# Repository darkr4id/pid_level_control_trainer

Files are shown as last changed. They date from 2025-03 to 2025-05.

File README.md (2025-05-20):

# MATLAB+Simulink based PID Fluid level control trainer - Bachelor Thesis project.
This repository contains all the materials associated with the Bachelor thesis project on a **MATLAB based PID Fluid level trainer**. The work focuses on developing and implementing a PID controller for fluid level regulation, with a detailed analysis presented in the thesis document.

## Table of Contents

- [Overview](#overview)
- [Project Structure](#project-structure)
- [Getting Started](#getting-started)
- [Usage](#usage)
- [Key Features](#key-features)
- [Results](#results)
- [Acknowledgements](#acknowledgements)
- [License](#license)

This repository contains the complete materials for the Bachelor thesis project titled "MATLAB based PID Fluid level trainer." The project focuses on designing and implementing a fluid level trainer using a MATLAB-based PID controller. The files in the repository include:

MATLAB Code: Scripts and functions for implementing the PID controller, running simulations, and analyzing fluid level control.
Supporting Materials: MATLAB Code, Simulink Models, and supplementary documentation that support the thesis findings.
Additionally a GUI program is included to run both the simulations and the experiment methods in a graphical environment.* 
The project demonstrates the practical application of control theory using MATLAB, where a PID controller is developed and tuned to regulate the fluid level in a training environment.

## Overview

This project explores the design, simulation, and implementation of a Proportional-Integral-Derivative (PID) controller to regulate fluid levels in a training setup. The main objectives include:

- **Design and Simulation:** Creating a model of the fluid level system in MATLAB.
- **PID Tuning:** Experimenting with different PID parameters to achieve optimal performance.
- **Analysis:** Documenting system responses and comparing simulation results with theoretical expectations.
- **Implementation:** Integrating the PID controller within a practical fluid level training system.

## Project Structure

The repository is organized as follows:

- README.md : This file
- p_f2.m : Main automation script
- pid_exp.slx : Main experimental simulink model
- pid_sim.slx : Main simulation model
- gui_pid_simulation_2.m : GUI Program for the project (Beta)

To run the MATLAB Simulink models and explore the PID controller design:

1. **Clone the repository:**

   ```bash
   git clone https://github.com/darkr4id/pid_level_control_trainer.git
   cd pid_level_control_trainer
2. **Open MATLAB:**

Navigate to the matlab/ directory and open the primary simulation script (pid_sim.slx) and the experimental simulink model (pid_exp.slx).
GUI Program at 
Run the Simulation:

**Important**
The experimental setup is designed using a Arduino UNO R4, therefore its essential for any replications of the setup to have the same microcontroller or for the Simulink external mode settings to be adjusted according to the controller used.
Motor Driver: L298N
Pump: Brushed DC pump of 12V (Exact model can be found on the Thesis Defence presentation)

**Important**
The GUI program was in the beta version as of 2025 May, no further development would be available for it due to time constraints and due to me finally moving on from this project to my master, but the GUI program worked just fine except for some minute errors in handling the experimental mode with multiple gain combos.

Execute the script in MATLAB. Make sure you have the necessary toolboxes installed, Arduino Support package for simulink and matlab, Digital signal processing toolbox. Adjust the PID parameters in p2_f.m when running the script.

Usage
Simulation: Run the fluid_level_simulation.m script to simulate the fluid level control.
Analysis: Check the generated plots and logs for performance analysis.
Experimentation: Modify the PID gains in the pid_controller.m file to observe different system responses.
Key Features
PID Controller Implementation: Robust PID algorithm tailored for fluid level control.
Simulation Environment: Detailed MATLAB simulation of a fluid tank system.
Data Analysis: Integrated tools for performance evaluation with plots and data logging.
Documentation: Comprehensive thesis report and supplementary documentation to support the findings.
Results
The project demonstrates successful control of fluid level dynamics using the PID controller. The simulation results indicate that with appropriate tuning, the system can maintain the fluid level within desired limits while responding effectively to disturbances.

## Acknowledgements
Special thanks to supervisors Prof Frank Platte and Dr. Peter Henselder, friends and family that supported this project. 

* In the GUI program specifically when its in the experimental mode at times it had issues with communicating with Matlab, but this can mostly be resolved by resetting the Arduino and relaunching Matlab.

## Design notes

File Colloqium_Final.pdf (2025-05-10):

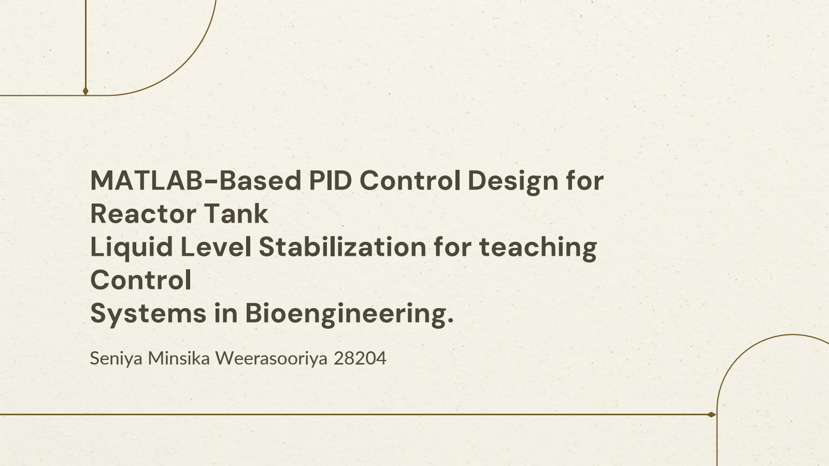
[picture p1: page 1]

# MATLAB-Based PID Control Design for

# Reactor Tank

# Liquid Level Stabilization for teaching Control

Systems in Bioengineering.

Seniya Minsika Weerasooriya 28204

# Introduction

01

1

# Fluid Level Control Systems

## Why do we need them?

- Provides hands on experience with different control strategies.
- Study the effects of varying Proportional, Integral and Derivative gains.
- Ensures the product quality by precise control of fluid levels in operations
- Ensures safety by preventing of overflows and other equipment malfunctions and overall stability of the system.

## Educational Significance

# Commercially available solutions

- Used to teach and demonstrate P, PI and PID control systems.
- Gunt RT 10
- Amatrol Level/Flow Process Control Troubleshooting Training System
- Prohibitive device cost
- Difficult to acquire for some institutions due to logistical complications.

## Purpose

## Commercially available liquid level control trainers

## Drawbacks

Fig 1 Gunt RT 10

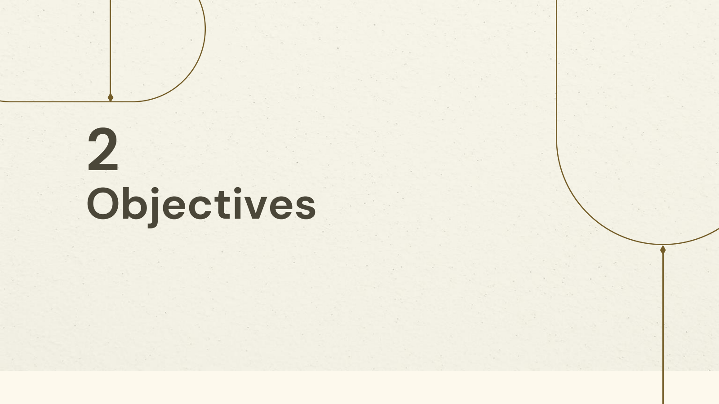
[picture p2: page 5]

# Objectives

2

# Objectives

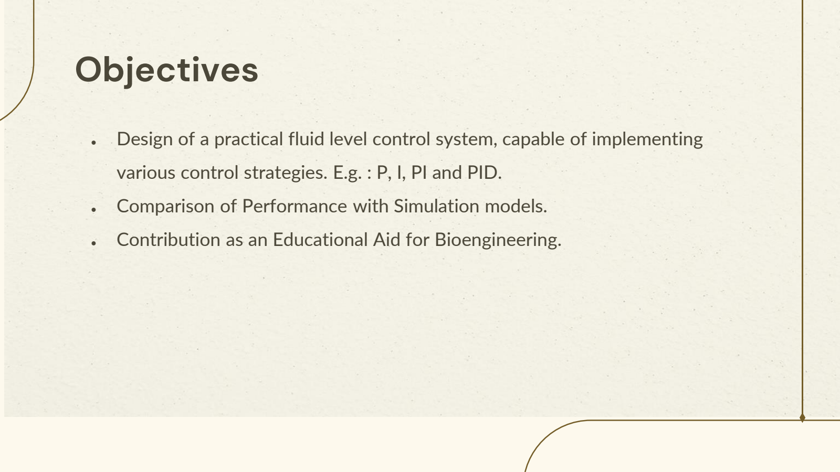
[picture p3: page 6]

- Design of a practical fluid level control system, capable of implementing various control strategies. E.g. : P, I, PI and PID.
- Comparison of Performance with Simulation models.
- Contribution as an Educational Aid for Bioengineering.

# Theoretical framework

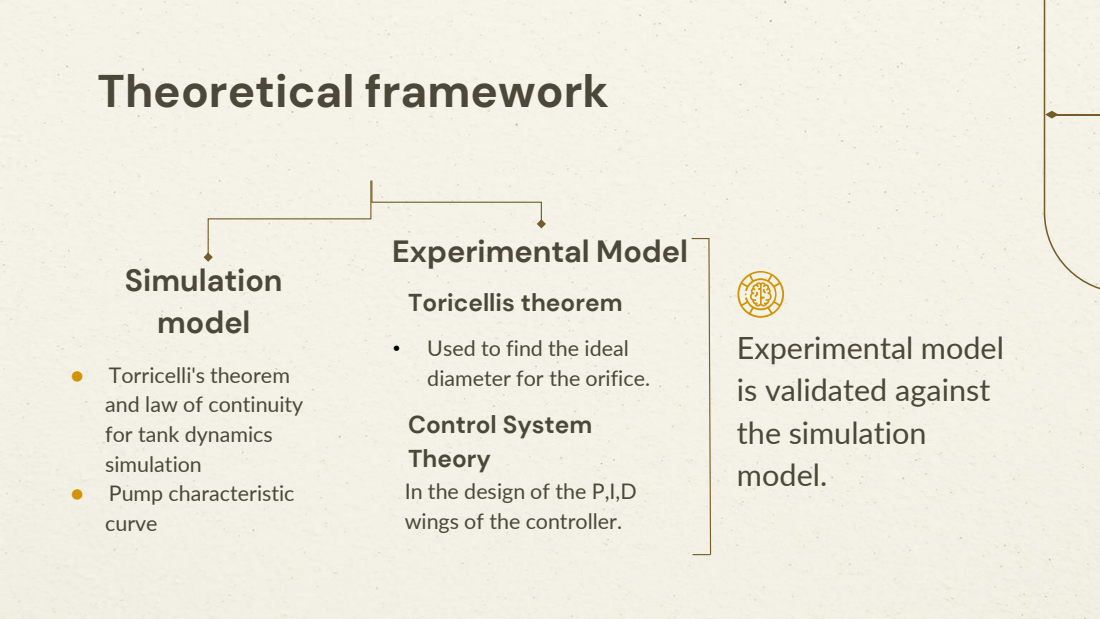
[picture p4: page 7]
Simulation model

Experimental Model
Toricellis theorem
• Used to find the ideal
diameter for the orifice.
Control System
Theory
In the design of the P,I,D
wings of the controller.

Experimental model
is validated against
the simulation
model.

● Torricelli's theorem
and law of continuity
for tank dynamics
simulation
● Pump characteristic
curve

# Design and Implementation

3

# The process :Experimental Setup

## Main Components

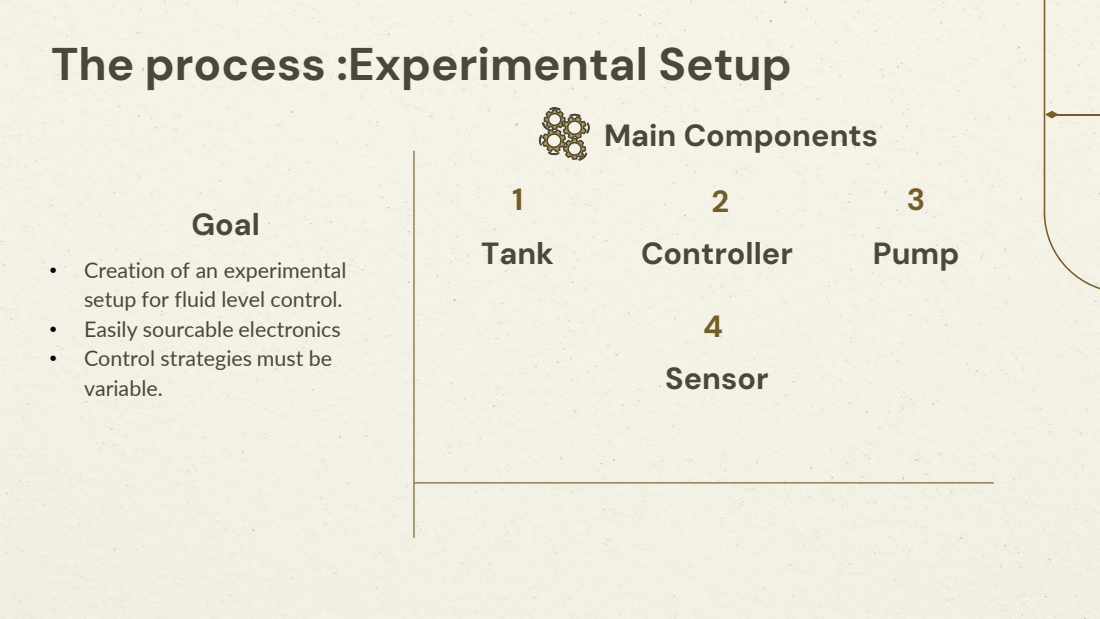
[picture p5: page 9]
Goal; Tank; Controller; Pump; Sensor

• Creation of an experimental
setup for fluid level control.
• Easily sourcable electronics
• Control strategies must be
variable.

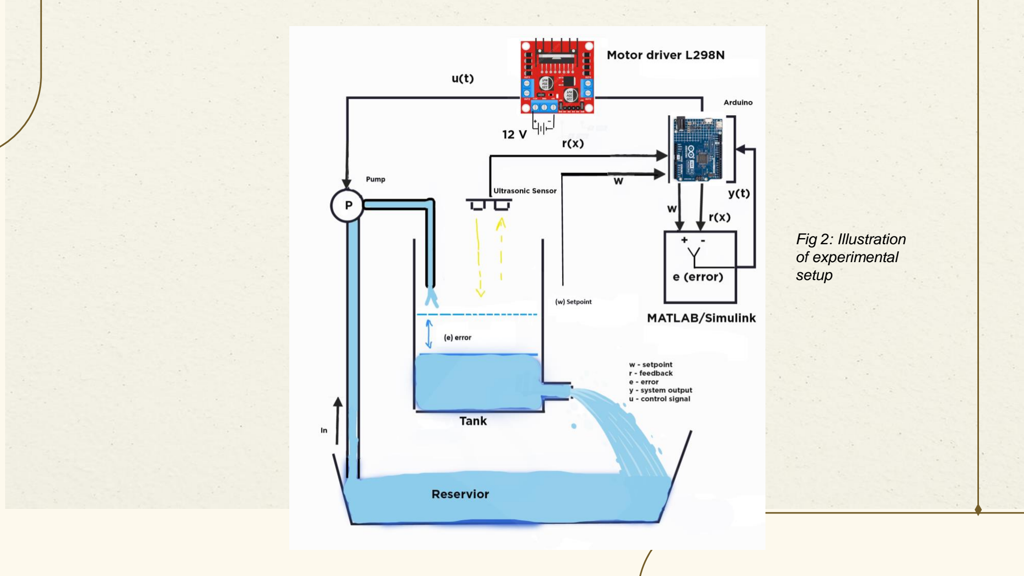
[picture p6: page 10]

Fig 2: Illustration
of experimental
setup

# Tank

- Glass tank with an orifice drilled on the bottom.
- Diameter = 15 cm
- Original orifice diameter = 14 mm
- Height = 0.2 m
- Printed orifice diameter = 4 mm (design), 3.5 mm (experimental)

### Custom Designed Outflow Pipe

# Experimental Model (Hardware Design)

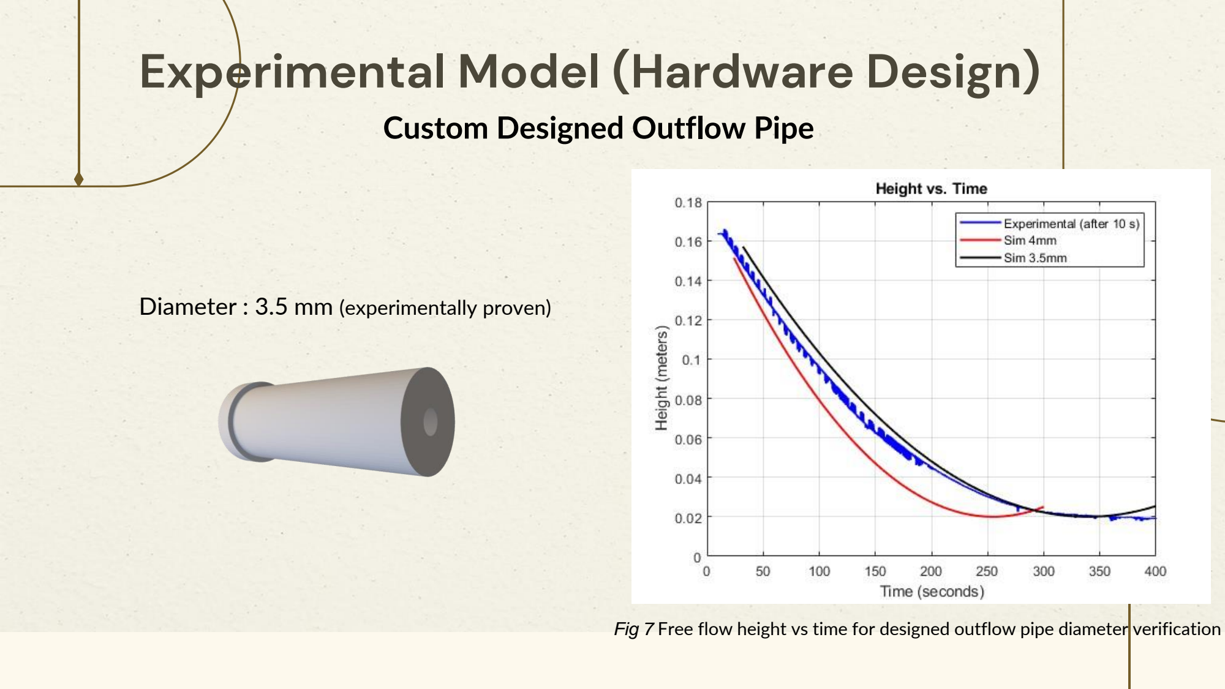
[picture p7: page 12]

Diameter : 3.5 mm (experimentally proven)

Fig 7 Free flow height vs time for designed outflow pipe diameter verification

# Controller

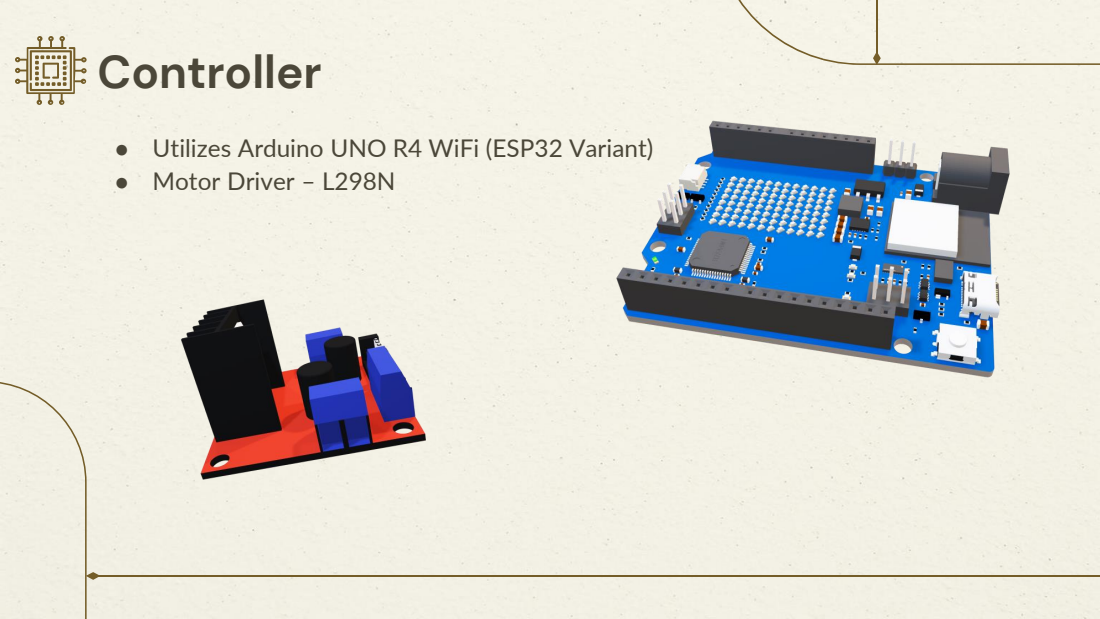
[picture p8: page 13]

● Utilizes Arduino UNO R4 WiFi (ESP32 Variant)
● Motor Driver – L298N

# Pump

- R385 Diaphragm Pump 12V
- Max flow rate
23 mL/sec experimental value
*26 ml/sec in datasheet

# Sensor

- SR04 Ultrasonic Sensor | Fig 3 Pumping curve for R385

Fig 4 R385

Fig 5 SR04 Ultrasonic Sensor

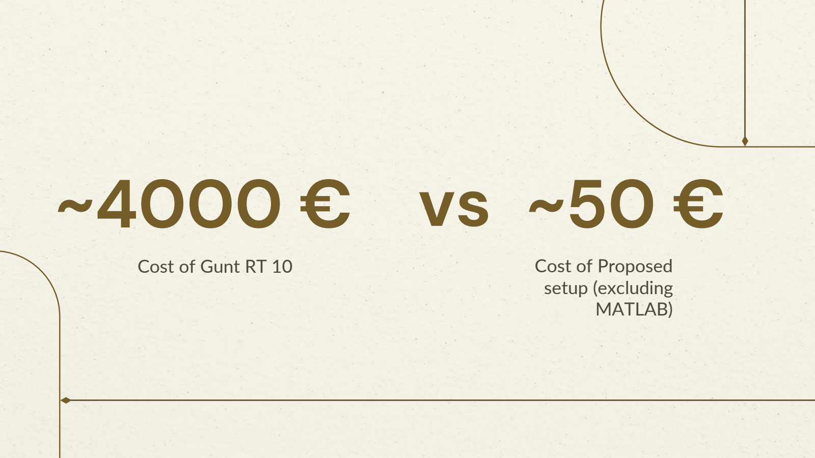
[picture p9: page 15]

~4000 €

Cost of Gunt RT 10

~50 €

Cost of Proposed
setup (excluding
MATLAB)

vs

# Methodology

4

# Nonlinear Simulation Model

# Nonlinear Simulation Model

Control Strategy (P/I/D)

# Nonlinear Simulation Model

Pump Dynamics Simulation

# Nonlinear Simulation Model

Tank dynamics Simulation

- A = pi*(0.15^2)/4 (Diameter of tank)
- a = pi*(0.0035^2)/4 (Outflow diameter)
- | C = a*sqrt(2*9.8) | (a* 2g)

# The Experimental model

Fig 6 Experimental Setup

# Experimental Model (Simulink Model)

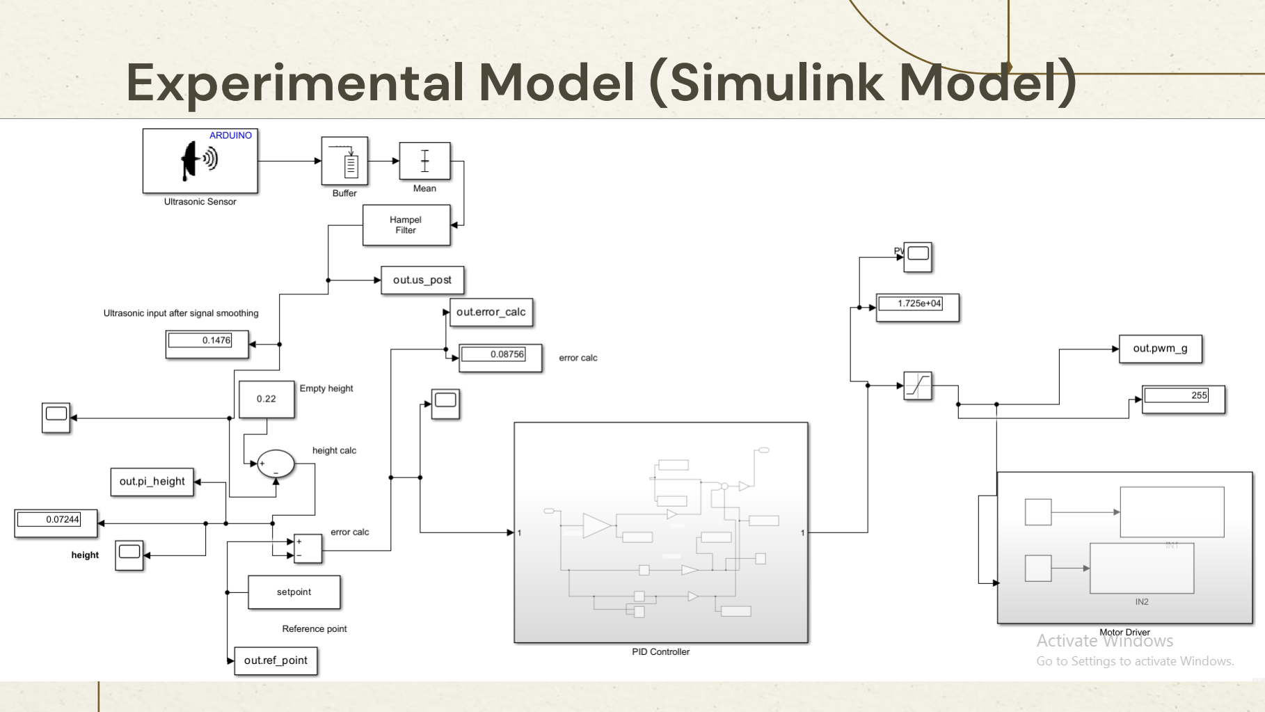
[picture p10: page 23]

Pump Dynamics Simulation

# Experimental Model (Simulink Model)

US Sensor input and Signal Processing for Noise reduction and Outlier elimination

# Experimental Model

Height and Error calculation from Ultrasonic data

# Experimental Model

PID Controller

# Experimental Model

PID Controller Subsystem

# Experimental Model

PWM to Pump

# Experimental Model

PWM Input

Motor ON/OFF and
Polarity control

### Tank Cover

# Experimental Model (Hardware Design)

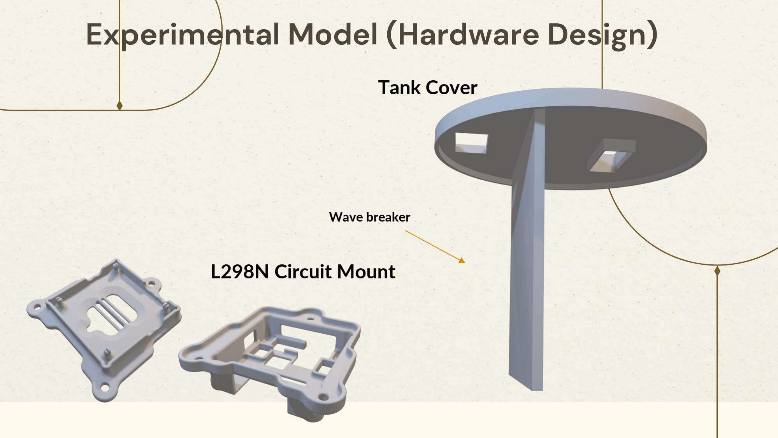
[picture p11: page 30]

### L298N Circuit Mount

Wave breaker

# Automation of Experiments

Fig 8 Automation Script code snippet

# Remote Execution of

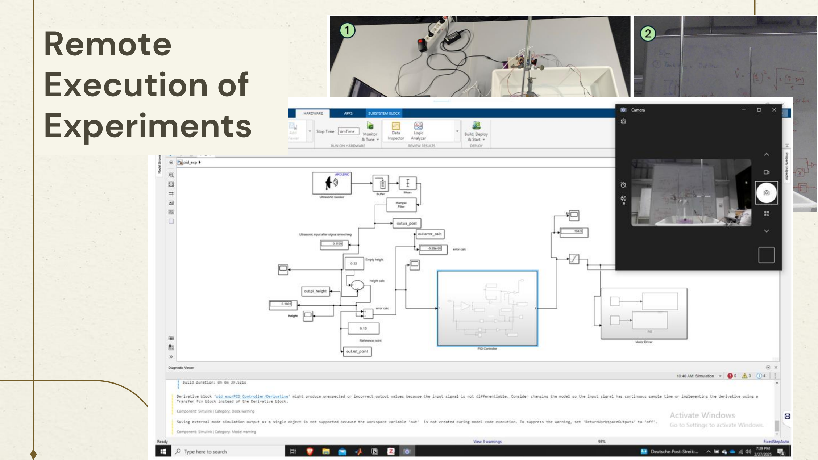
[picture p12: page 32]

# Experiments

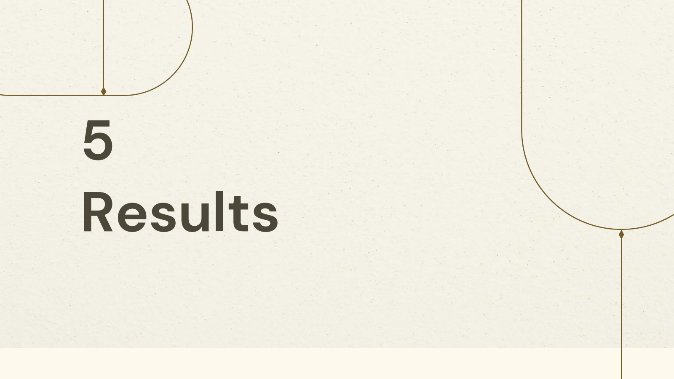
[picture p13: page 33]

# Results

5

# ON OFF Control

Fig 9(L),10(R) Height vs time; Error vs time. ON OFF Control setpoint = 0.1 m

# P Control

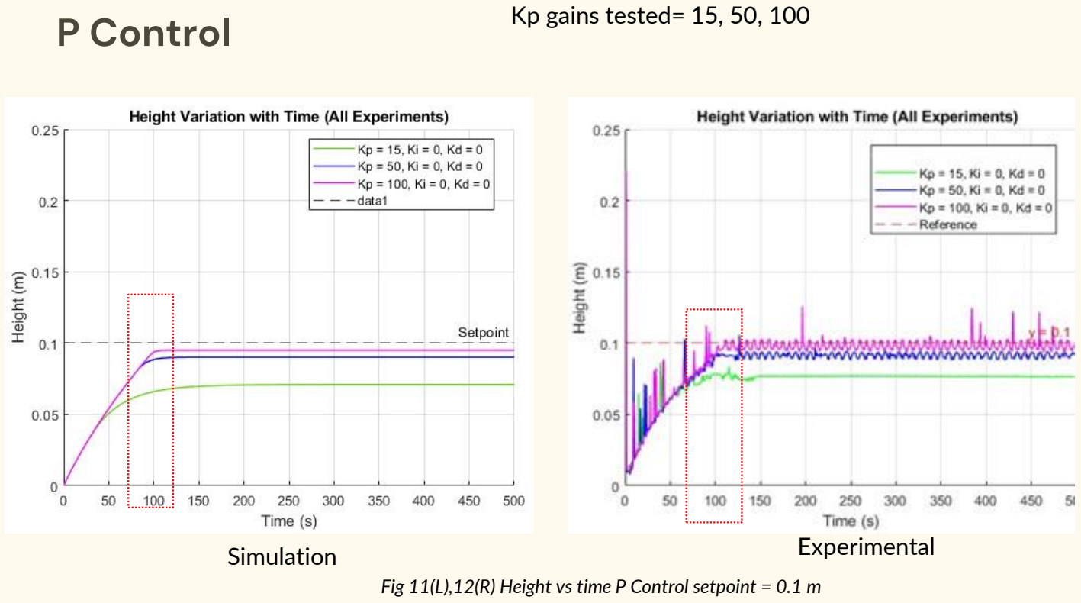
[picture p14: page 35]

Simulation | Experimental

Kp gains tested= 15, 50, 100

Fig 11(L),12(R) Height vs time P Control setpoint = 0.1 m

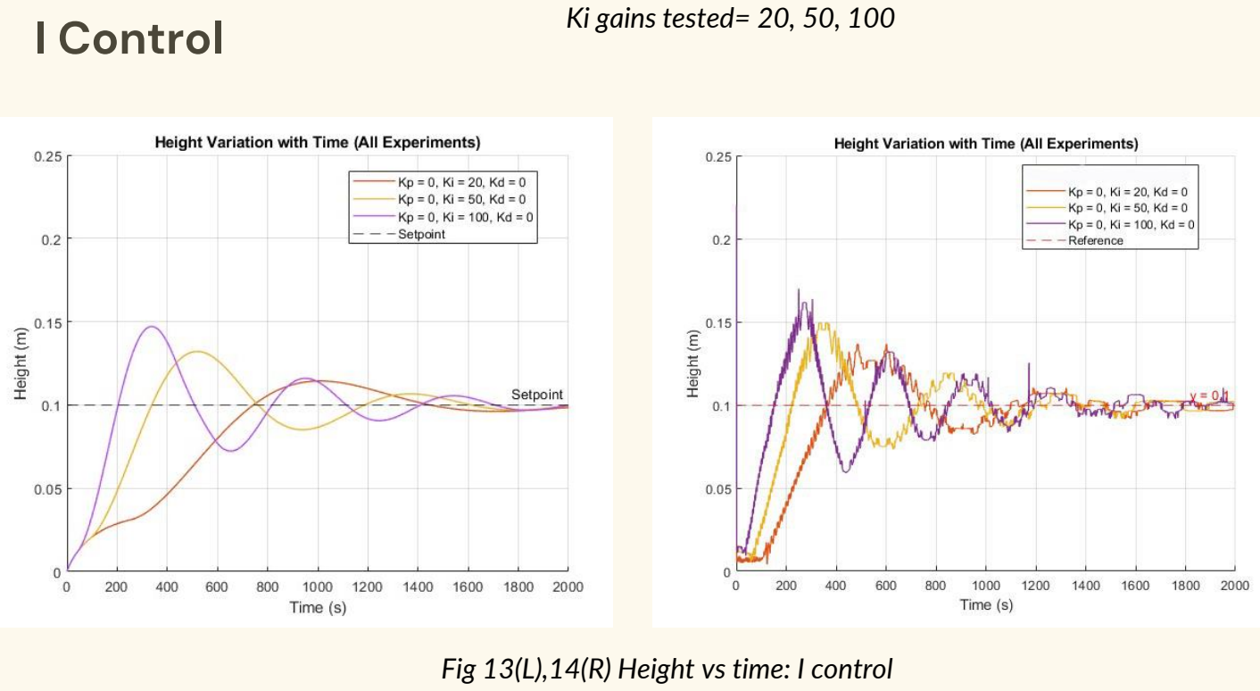
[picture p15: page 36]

I Control | Ki gains tested= 20, 50, 100

Fig 13(L),14(R) Height vs time: I control

# I controller (Ki = 20)

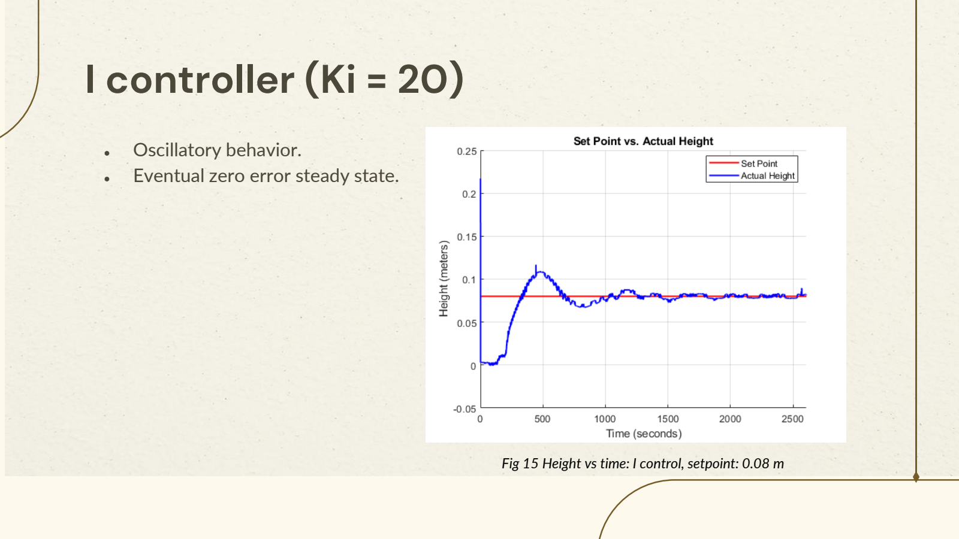
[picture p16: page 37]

- Oscillatory behavior.
- Eventual zero error steady state.

Fig 15 Height vs time: I control, setpoint: 0.08 m

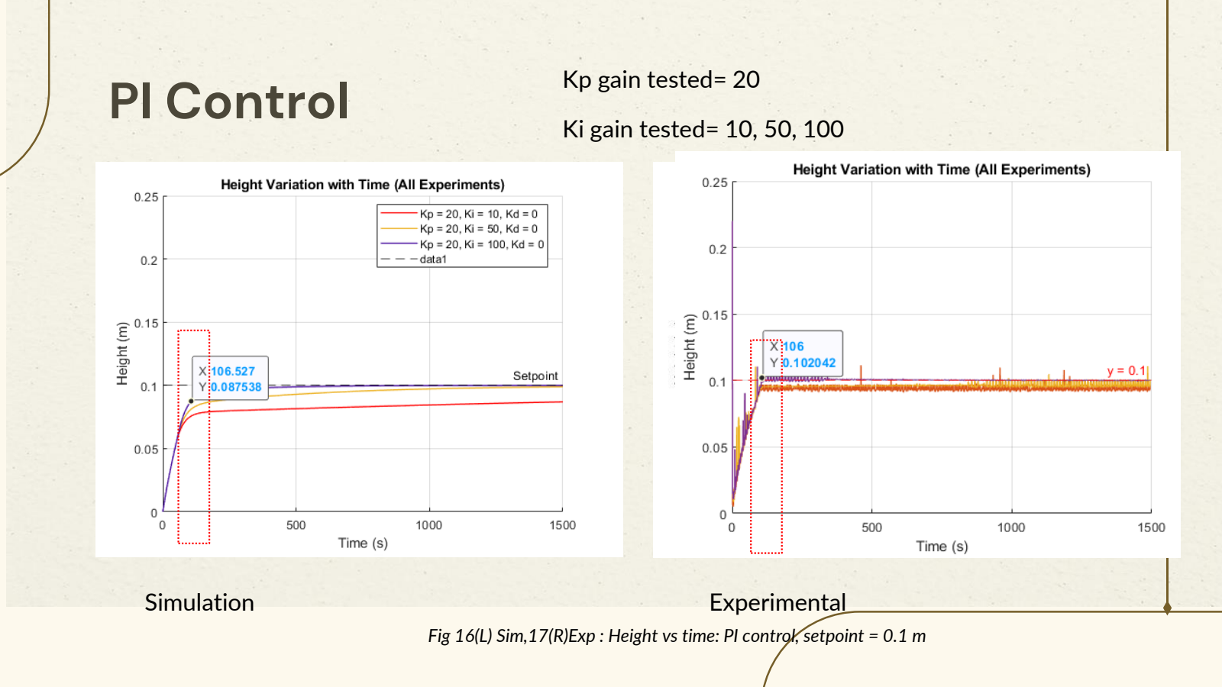
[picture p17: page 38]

PI Control | Kp gain tested= 20
| Ki gain tested= 10, 50, 100
Simulation | Experimental

Fig 16(L) Sim,17(R)Exp : Height vs time: PI control, setpoint = 0.1 m

# Kp = 15, Ki = Varying Kp gains tested= 15

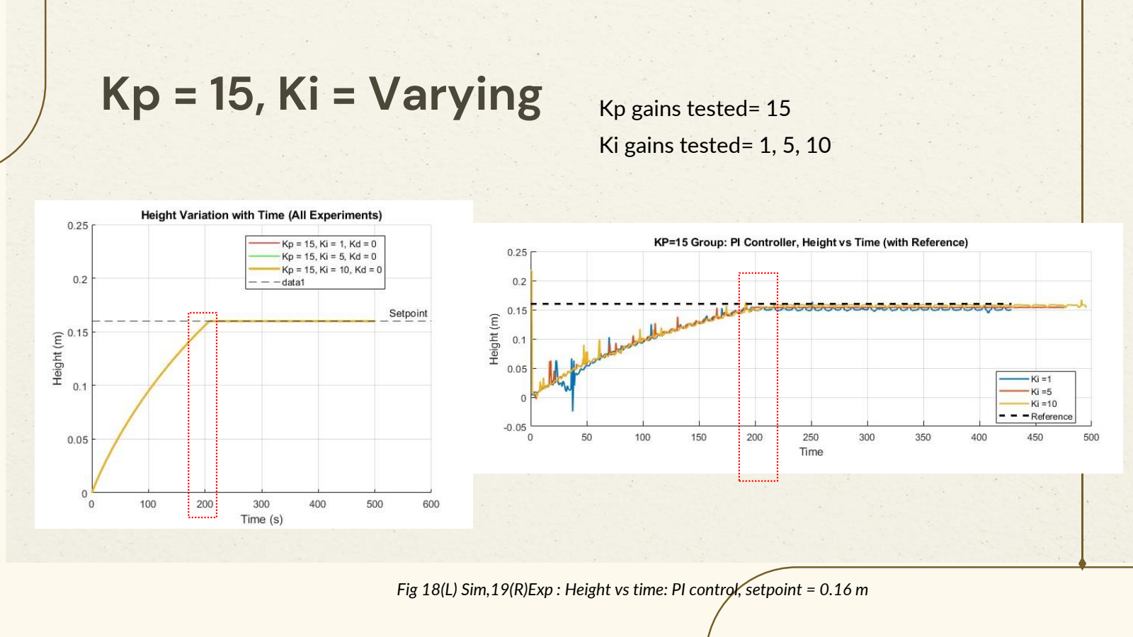
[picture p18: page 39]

Ki gains tested= 1, 5, 10

Fig 18(L) Sim,19(R)Exp : Height vs time: PI control, setpoint = 0.16 m

# P & I contributions (Kp = 15, Ki = 10)

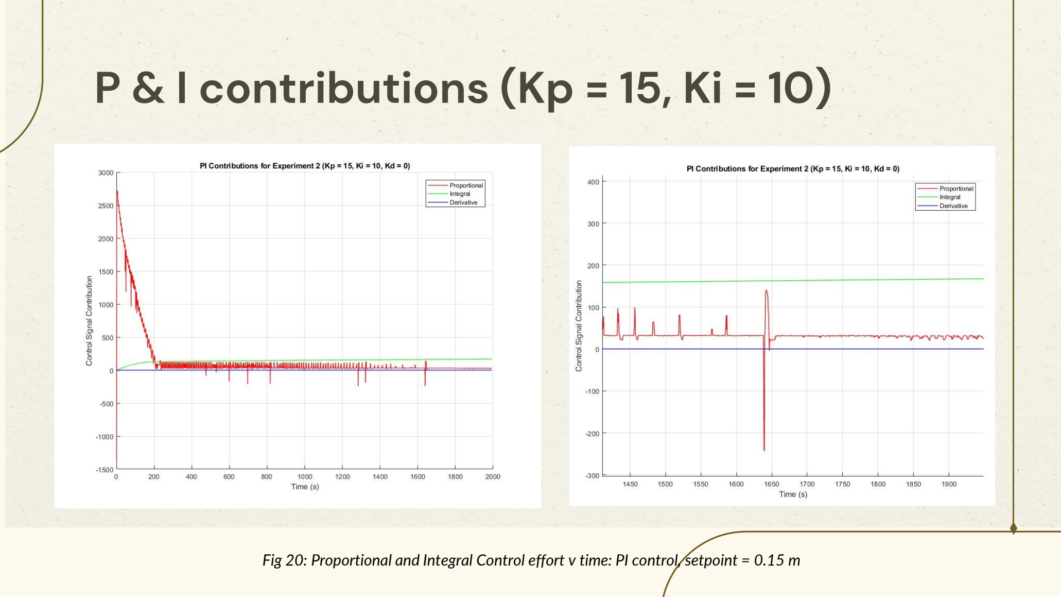
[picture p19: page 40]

Fig 20: Proportional and Integral Control effort v time: PI control, setpoint = 0.15 m

# PI controller Response Study ● 1 – setpoint = 0.16 m

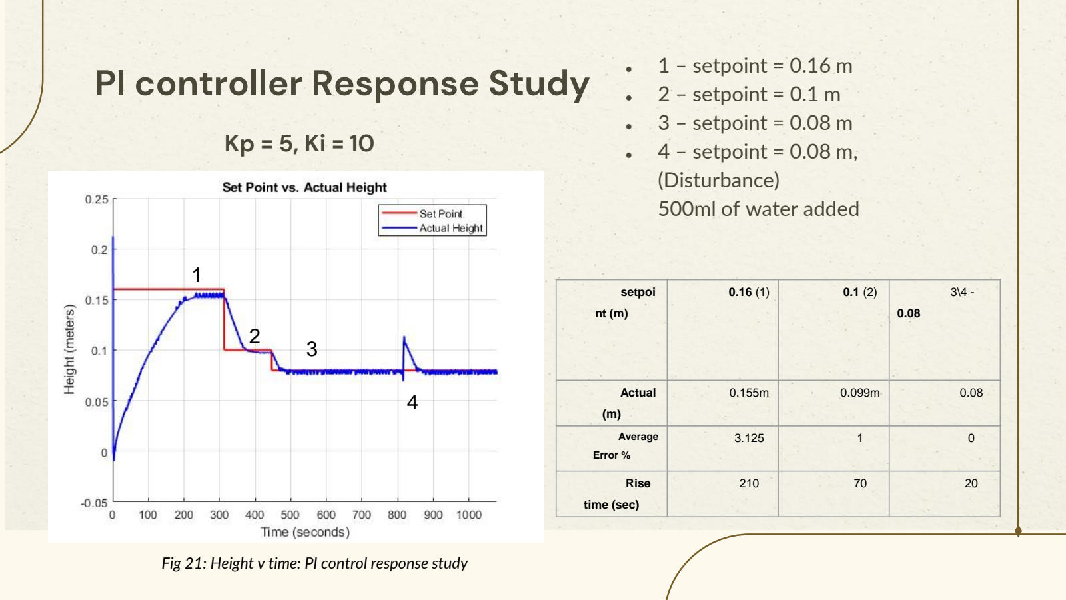
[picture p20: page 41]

- 2 – setpoint = 0.1 m
- 3 – setpoint = 0.08 m
- 4 – setpoint = 0.08 m,
(Disturbance)
500ml of water added

1

2
3

4

setpoi nt (m) | 0.16 (1) | 0.1 (2) | 3\4 -0.08
Actual (m) | 0.155m | 0.099m | 0.08
Average Error % | 3.125 | 1 | 0
Rise time (sec) | 210 | 70 | 20

### Kp = 5, Ki = 10

Fig 21: Height v time: PI control response study

# PID Control

Simulation | Experimental

Fig 22(L) Sim,23(R)Exp : Height vs time: PID control, setpoint = 0.15 m

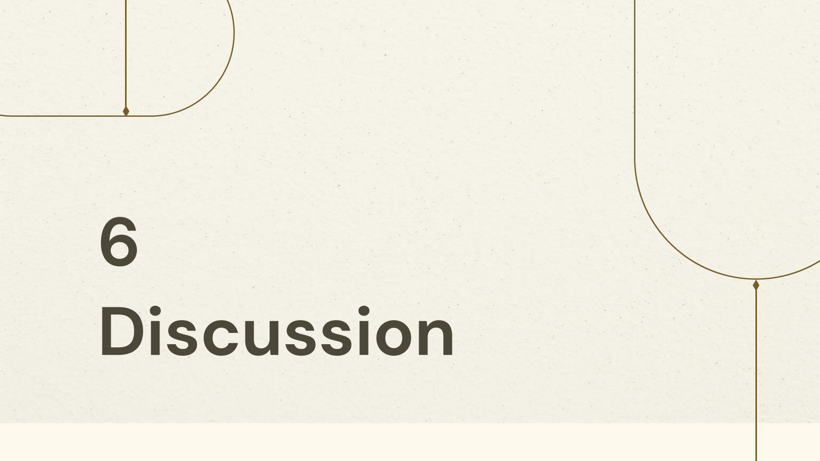
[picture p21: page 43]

# Discussion

6

# Overview of the Controllers

- ON OFF Controller: maintained around the setpoint although it had constant oscillations.
- P controller: reached the setpoint at higher Kp levels.
- I controller: Higher Ki, introduced more overshoot and oscillations.
- PI Controller: Best option
- PID Controller: Identical performance to PI controller as derivative action was not necessarily required for slow dynamics of fluid systems.

# As a Teaching tool

- Provides a hands on method to visualize concepts of fluid mechanics and control theory in action.
- A modular setup
- Remote execution ability gives more accessibility.

# Potential reasons for deviations in Simulations

- Ideal conditions were assumed for the simulations.
- Evidence of Turbulent flow
Re =

ρv L
μ

=
1000 ∗ 2∗ 9.81 ∗ 0.1 ∗ 0.0035 0.0010.0010005

### = 4900 (4000<Re : Turbulent flow)

- The pumping curve was linearized to model its dynamics into the simulation.

# GUI Interface (Beta)

Simulation Mode
- Automation of the simulation experiments

# GUI Interface

Simulation Mode:
Multiple Gain combinations

# GUI Interface

Experimental Mode
- Automation of the experiments

# Conclusion

- Simulation predictions closely match the experimental outcomes overall.
- Effects of various control strategies can be seen from the results.
- Cost effective design and provides a practical teaching tool.

## Future work

- Investigate LIDAR sensors for distance measurement, which could provide less noise.
- Implement the practical setup in a learning environment for student feedback.
- Incorporate adaptive control strategies.

# %The End Thank you!

# Questions

7

# Literature review

•Åström, K. J., & Hägglund, T. (2006). Advanced PID Control. ISA.
•O'Dwyer, A. (2009). Handbook of PI and PID Controller Tuning Rules. Imperial College Press. •Seborg, D. E., Edgar, T. F., & Mellichamp, D. A. (2010). Process Dynamics and Control (3rd ed.). Wiley.
•Franklin, G. F., Powell, J. D., & Emami-Naeini, A. (2015). Feedback Control of Dynamic Systems (7th ed.). Pearson.
•Nise, N. S. (2011). Control Systems Engineering (6th ed.). Wiley.
•Ogata, K. (2010). Modern Control Engineering (5th ed.). Prentice Hall.

# Resource Credits

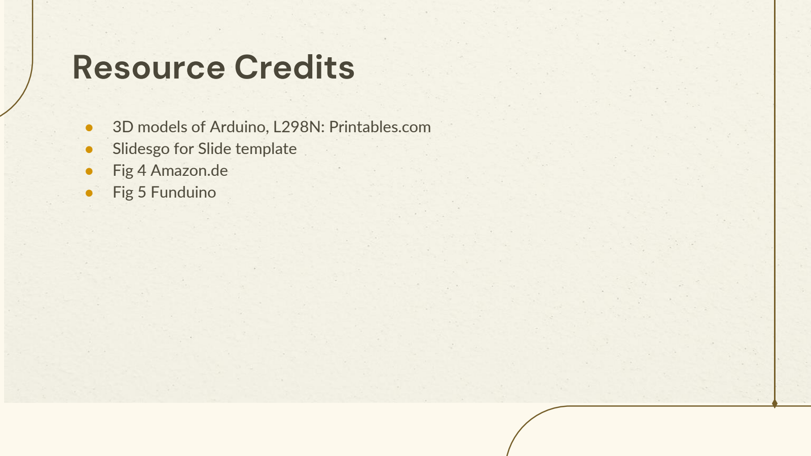
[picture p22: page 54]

- 3D models of Arduino, L298N: Printables.com
- Slidesgo for Slide template
- Fig 4 Amazon.de
- Fig 5 Funduino

# Kp = 15, Ki = 10

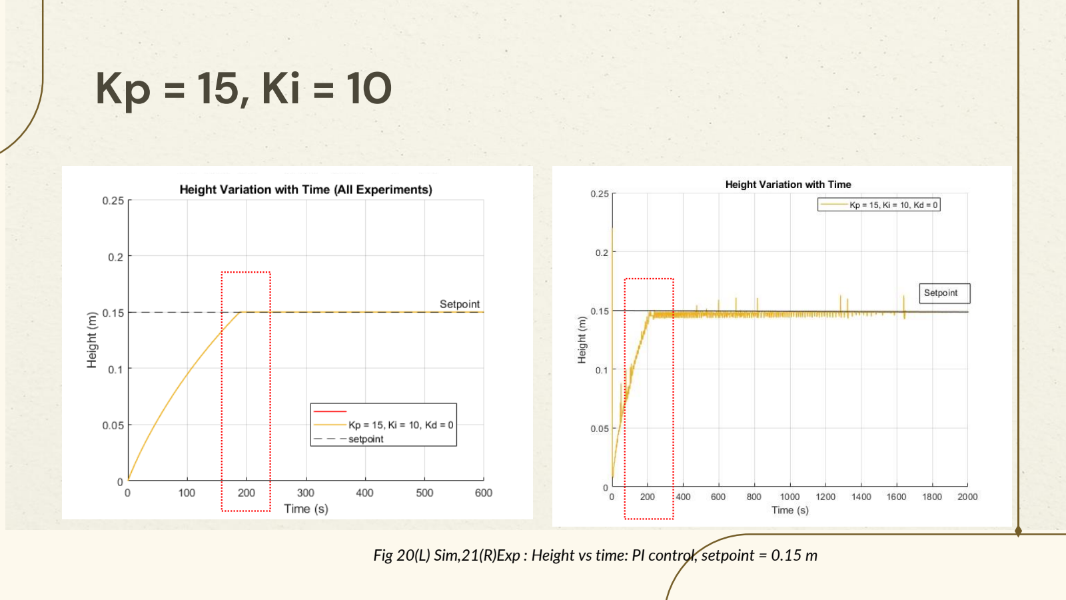
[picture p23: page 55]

Fig 20(L) Sim,21(R)Exp : Height vs time: PI control, setpoint = 0.15 m

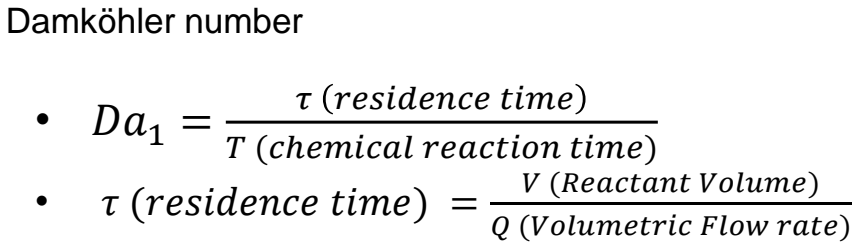
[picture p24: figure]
τ residence time; T (cℎemical reaction time) • τ (residence time) =; V (Reactant Volume); Q (Volumetric Flow rate); Damköhler number

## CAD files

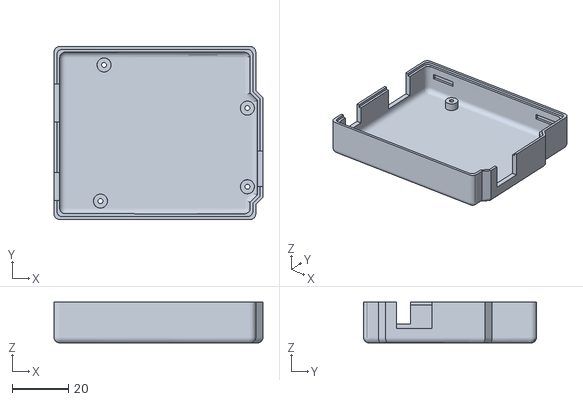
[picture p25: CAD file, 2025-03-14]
3D_models/3D_model_ArduinoMount/Case_Botton_V1.0.stl
74.1 x 61.3 x 14.5

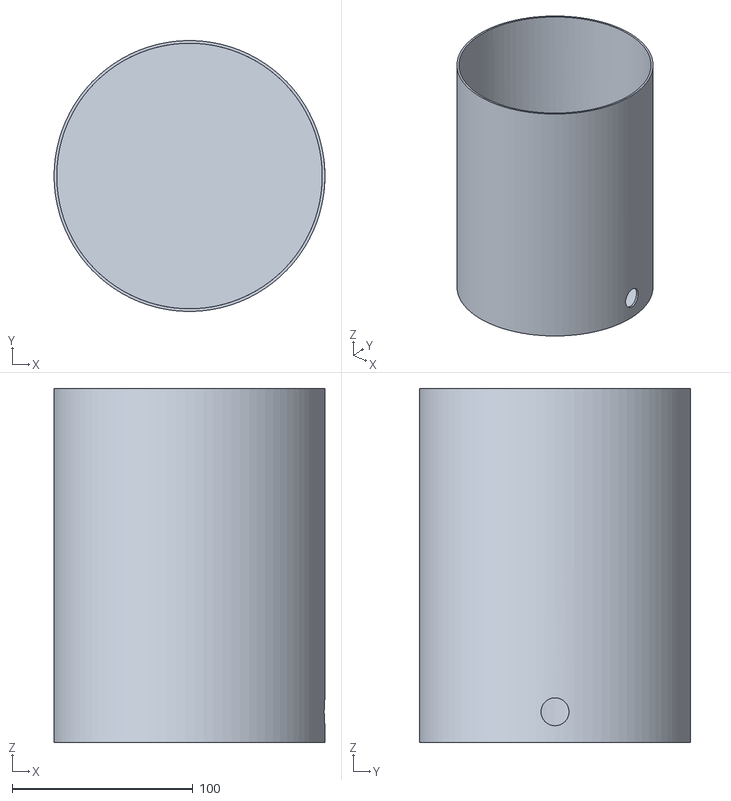
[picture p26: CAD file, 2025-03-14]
3D_models/tank v1.stl
150.0 x 149.9 x 196.0

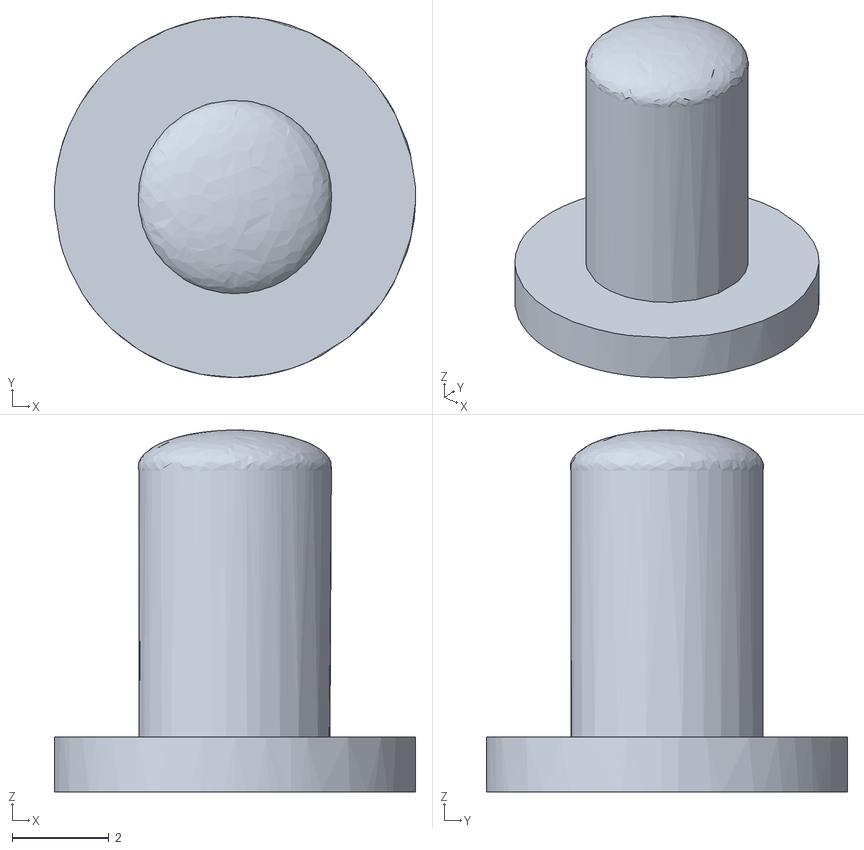
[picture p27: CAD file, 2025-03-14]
3D_models/3D_model_ArduinoMount/Button_V1.0.stl
7.48 x 7.48 x 7.50

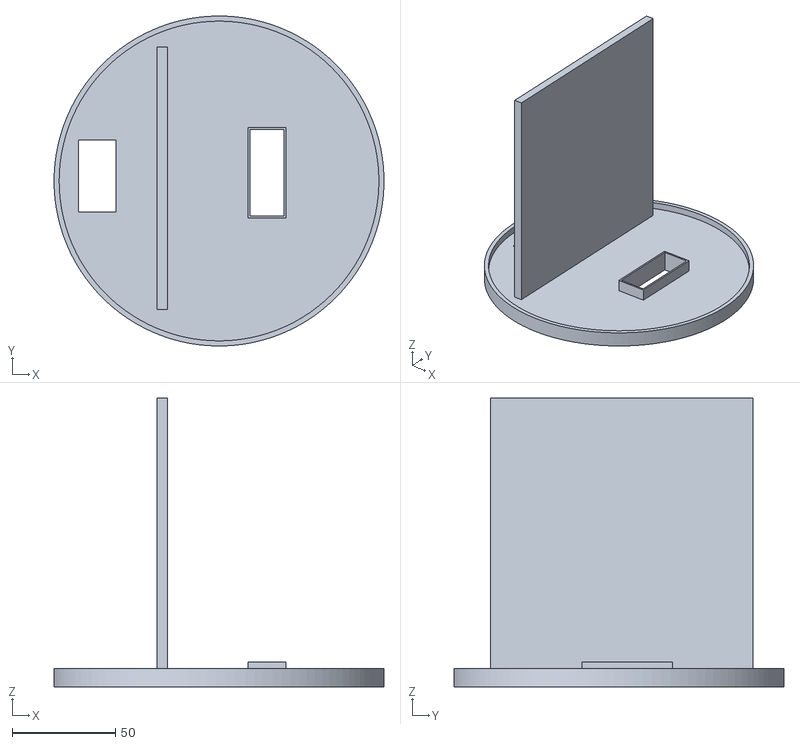
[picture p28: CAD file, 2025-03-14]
3D_models/Cover_tank v2.stl
160.0 x 160.0 x 140.0

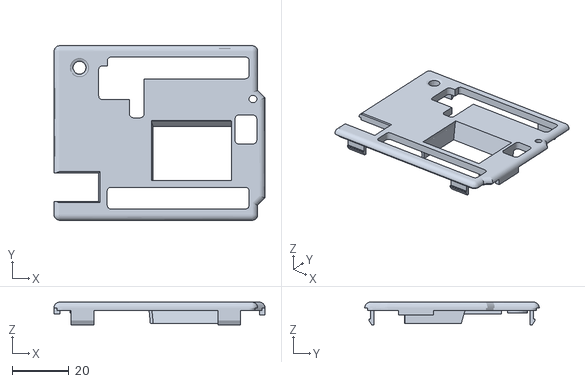
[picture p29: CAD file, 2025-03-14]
3D_models/3D_model_ArduinoMount/Case_Top_V1.0.stl
74.1 x 61.3 x 8.00

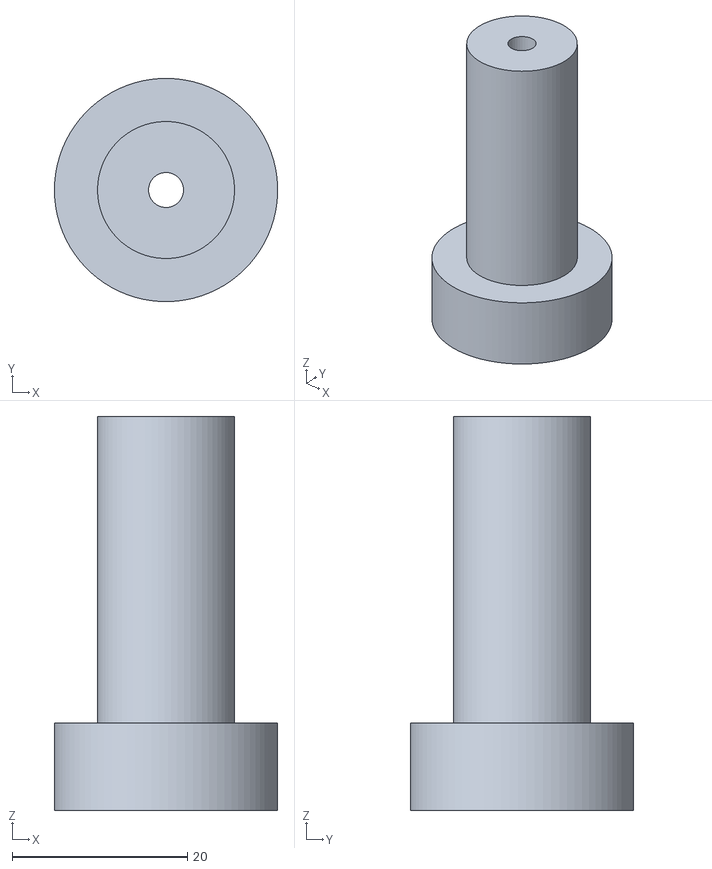
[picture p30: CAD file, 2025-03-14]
3D_models/Outflow v2_withstopper v1.stl
25.5 x 25.5 x 45.0
